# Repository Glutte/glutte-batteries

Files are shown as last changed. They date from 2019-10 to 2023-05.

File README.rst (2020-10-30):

Mesure de l'état de charge de la batterie
=========================================

Les nouvelles (juillet 2019) batteries au plomb nécessitent une nouvelle
approche pour mesurer leur état de charge.

Mesurer la tension ne suffit pas, d'abord parce que la différence de tension
entre batterie pleine et vide est faible, d'autre part parce que la tension
mesurée dépend fortement du courant de dé-/charge.

Proposition
-----------

Mesurer le courant à intervalle régulier (p.ex. à 10Hz) et intégrer le courant
pour calculer une charge accumulée ou extraite de la batterie (A * s = Coulomb).

Besoins
-------

Quand le niveau de charge des batteries est trop bas, il faut couper des
consommateurs. Il est possible de commuter les groupes de consommateurs suivants:

- Balise 70cm
- Mode relais QRP/QRO
- Alimentation Relais
- Alimentation Raspberry Pi, WiFi et autres consommateurs 5V restants

Afin que le relais puisse indiquer le niveau de charge, un port série est
utilisé entre le coulomb-mètre et la glutt-o-matique (unidirectionnel). Pour la
surveillance ainsi que pour d'autres applications, un deuxième port série transmet
les mêmes informations à un Raspberry Pi connecté à Internet.

Le colomb-mètre doit donc comporter trois commutations à relais, qui peuvent à
leur tour commuter des relais de puissance.

Quelques définitions
--------------------

Tension nominale: Tension d'un élément chargé au repos à 25°C : 2.1V/élément soit
12.6V pour la traditionnelle batterie dite de 12V. C'est ce que vous devez lire
(à la précision de la mesure près) sur une batterie que vous avez chargée et
ensuite débranchée pendant une nuit.

Tension de floating (tension de charge d'entretien):
Tension à laquelle on peut maintenir en permanence un accumulateur
pour être sûr qu'il soit chargé au moment où en a besoin : 2.25 à 2.28/élément à
25°C. Cette valeur devrait être corrigée de 0.005V en plus ou en moins par degré
centigrade selon que la température descend ou monte.
A -10°C c'est 2.36V et à +40°C 2.21V.

Tension de recharge:
Tension maximum à laquelle on peut charger la batterie (mais pas la laisser en
permanence). 2.3 à 2.4V/élément toujours à 25°C et avec le même coefficient de
température de 0.005V/°C. Soit 13.8 à 14.4V pour un bloc 12V à 25°C.
Attention à prendre aussi en considération les pics de courte durée si la
tension est bruitée.

Evitez de décharger la batterie en dessous de 11.9V, car vous commencez à
décharger profondément la batterie.

Risque de gel: Une batterie profondément déchargée risque le gel!

+---------+---------------+------------------------+--------------------+
|  Baumé  | Densité H2SO4 | Etat de charge         | Température de gel |
+=========+===============+========================+====================+
| 13 à 23 | 1.099 à 1.190 | Profondément déchargée | entre -7C et -27C  |
+---------+---------------+------------------------+--------------------+
| 24 à 29 | 1.200 à 1.252 | Moyenne                | entre -27C et -52C |
+---------+---------------+------------------------+--------------------+
| 30 à 32 | 1.262 à 1.285 | Pleine                 | plus bas que -52C  |
+---------+---------------+------------------------+--------------------+

Composants
----------

Boitier: Hammond RZ0214C

Shunt: muRata 3020-01096-0

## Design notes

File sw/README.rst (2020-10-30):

Description logiciel
====================

Au démarrage, avant de passer à la mesure régulière, le code doit:

- Initialiser les GPIO
- Mettre en place un timer 100Hz pour pouvoir faire dormir le CPU
- Lire l'EEPROM pour charger le compteur mAh
  - Attention au risque de problemes après 100000 écritures
  - Faire une vérification lecture après écriture et communiquer le problème
- Mettre en place un watchdog
- Initialiser UART (uniquement TX, on verra si on a besoin du RX plus tard)
- Configurer SPI pour le LTC2400
- Initialiser entrées analogiques et mesurer tension batterie
- Initialiser entrée numérique D4 pour mesurer contacts auxiliaires des dijoncteurs des trois phases de l'éolienne.

Protocole du port série
-----------------------

Chaque message commence par un identificateur, suivi d'une virgule, du temps en
secondes, une virgule, un champ de données, et termine par CR LF.

+------------------+---------------------------------------------+
| Identificateur   | Contenu du champ                            |
+------------------+---------------------------------------------+
| `TEXT`           | Un message informatif                       |
| `ERROR`          | Erreur ou avertissement                     |
| `CAPA`           | Une valeur en mAh                           |
| `RELAY`          | Etats des trois relais, `On` ou `Off`       |
| `VBAT+`          | Une valeur en mV                            |
| `VBAT-`          | Une valeur en mV                            |
| `DISJEOL`        | `On` ou `Off`, état du disjoncteur eolienne |
+--------------------+-------------------------------------------+

Par exemple: `TEXT,12,Startup\r\n`

TODO
----

- Definir le comportement par defaut au démarrage, pas de glitch!

Reglages eFuse
--------------

- Low: Horloge crystal 8MHz ou plus, Startup time PWRDWN/RESET 1K/14CK + 4.1ms, diviseur /8 actif
- High: tout par défaut
- Ext: Brownout detector: 4.3V

Commande AVRdude equivalente: `-U lfuse:w:0x7e:m -U hfuse:w:0xd9:m -U efuse:w:0xfc:m`

Remarques
---------

- Le DS18B20 ne sera pas assemblé, l'entrée D4 et son footprint réutilisés pour brancher les auxiliaires des
  disjoncteurs de l'éolienne

Acknowledgements
================

Le dossier `lib/` contient des fichiers des bibliotheques suivantes:

- OneWire https://github.com/PaulStoffregen/OneWire
- DallasTemperature https://github.com/milesburton/Arduino-Temperature-Control-Library.git
- avr-uart https://github.com/andygock/avr-uart
- Code exemple LTC2400 de l'application note correspondante

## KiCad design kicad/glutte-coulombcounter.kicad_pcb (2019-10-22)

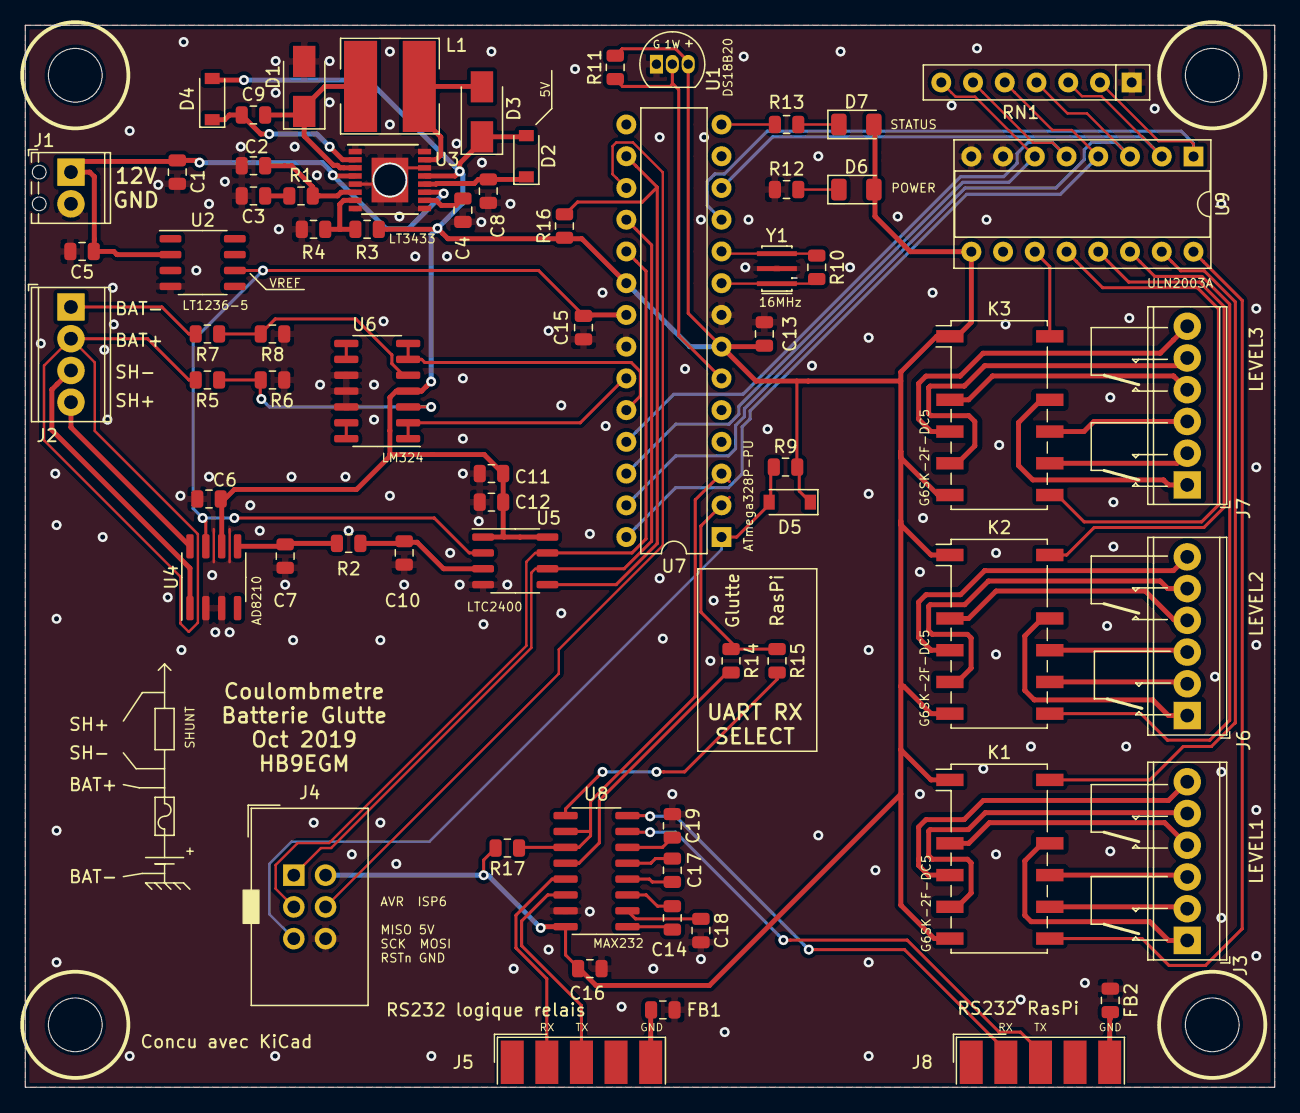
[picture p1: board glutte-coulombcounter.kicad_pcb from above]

Board: 2 copper layers, 100.0 x 85.0 mm, 72 parts (0 on the bottom side), 81 nets.

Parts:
C1: 2.2u; C_0805_2012Metric
C2: 330p; C_0805_2012Metric
C3: 1000p; C_0805_2012Metric
C4: 0.01u; C_0805_2012Metric
C5, C6, C8, C9, C13, C15: 0.1u; C_0805_2012Metric
C7, C10: DNF; C_0805_2012Metric
C11: 4.7u; C_0805_2012Metric
C12: 0.1uF; C_0805_2012Metric
C14, C16, C17, C18, C19: 1u; C_0805_2012Metric
D1: B160-E3; D_SMA
D2, D4, D5: 1N4148; D_SOD-123
D3: B120-E3; D_SMA
D6: LED_PWR; LED_1206_3216Metric
D7: LED_STATUS; LED_1206_3216Metric
FB1, FB2: DNF; L_0805_2012Metric
H1, H2, H3, H4: M4; MountingHole_4.3mm_M4
J1: 12V; TerminalBlock_Phoenix_MPT-0,5-2-2.54_1x02_P2.54mm_Horizontal
J2: Measure; TerminalBlock_Phoenix_MPT-0,5-4-2.54_1x04_P2.54mm_Horizontal
J3: K1; TerminalBlock_Phoenix_MPT-0,5-6-2.54_1x06_P2.54mm_Horizontal
J4: AVR-ISP-6; IDC-Header_2x03_P2.54mm_Vertical
J5: Glutte; DSUB-9_Male_EdgeMount_P2.77mm
J6: K2; TerminalBlock_Phoenix_MPT-0,5-6-2.54_1x06_P2.54mm_Horizontal
J7: K3; TerminalBlock_Phoenix_MPT-0,5-6-2.54_1x06_P2.54mm_Horizontal
J8: Raspi; DSUB-9_Male_EdgeMount_P2.77mm
K1, K2, K3: G6SK-2F-DC5; Relay_DPDT_Omron_G6SK-2F
L1: 100uH; Sumida_CDRH6D28
R1: 68k; R_0805_2012Metric
R2: 51; R_0805_2012Metric
R3: 300k; R_0805_2012Metric
R4: 97.6k; R_0805_2012Metric
R5, R7: 300k/1%; R_0805_2012Metric
R6, R8: 100k/1%; R_0805_2012Metric
R9: 10k; R_0805_2012Metric
R10: 1M; R_0805_2012Metric
R11, R16, R17: 4k7; R_0805_2012Metric
R12, R13: 330; R_0805_2012Metric
R14: 0R; R_0805_2012Metric
R15: DNF; R_0805_2012Metric
RN1: 2k2; R_Array_SIP7
U1: DS18B20; TO-92_Inline
U2: LT1236-5; SO-8_3.9x4.9mm_P1.27mm
U3: LT3433; TSSOP-16-1EP_4.4x5mm_P0.65mm
U4: AD8210; SOIC-8_3.9x4.9mm_P1.27mm
U5: LTC2400; SO-8_3.9x4.9mm_P1.27mm
U6: LM324; SOIC-14_3.9x8.7mm_P1.27mm
U7: ATmega328P-PU; DIP-28_W7.62mm
U8: MAX232; SOIC-16_3.9x9.9mm_P1.27mm
U9: ULN2003A; DIP-16_W7.62mm_Socket
Y1: CSTNE16M0V530000R0; Resonator_SMD_muRata_CSTxExxV-3Pin_3.0x1.1mm_HandSoldering

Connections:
+5VA: C6.1, C11.1, C12.1, C13.1, C16.1, D2.2, D3.1, D4.2, D5.1, D6.2, D7.2, J4.2, K1.1, K1.6, K2.1, K2.6, K3.1, K3.6, R3.2, R9.2, R11.2, R16.1, R17.2, U1.3, U3.13, U4.6, U5.1, U5.8, U6.4, U7.7, U7.20, U8.16, U9.9
+12V: C1.1, C5.1, J1.1, U2.2, U3.4, U3.11
+BATT: J2.2, R5.2
-BATT: J2.1, R7.2
/1WIRE: R11.1, U1.2, U7.6
/ADC0: U6.1, U6.2, U7.23
/ADC1: U6.6, U6.7, U7.24
/MISO: J4.1, U5.6, U7.18
/MOSI: J4.4, U7.17
/RESETn: D5.2, J4.5, R9.1, U7.1
/RXD: R14.1, R15.1, U7.2
/Relays/K1_RESET: RN1.2, U7.11, U9.1
/Relays/K1_SET: RN1.3, U7.12, U9.2
/Relays/K2_RESET: RN1.4, U7.27, U9.3
/Relays/K2_SET: RN1.5, U7.28, U9.4
/Relays/K3_RESET: RN1.6, U7.25, U9.5
/Relays/K3_SET: RN1.7, U7.26, U9.6
/SCK: J4.3, U5.7, U7.19
/SHUNT+: J2.4, U4.8
/SHUNT-: J2.3, U4.1
/SSn: R16.2, U5.5, U7.16
/STATUS: R13.2, U7.14
/TXD: R17.1, U7.3, U8.10, U8.11
GNDA: C1.2, C2.2, C3.2, C4.2, C5.2, C6.2, C7.2, C8.1, C10.2, C11.2, C12.2, C13.2, C15.2, C16.2, C18.2, C19.1, D1.2, FB1.1, FB2.1, J1.2, J4.6, R4.1, R6.1, R8.1, R12.1, RN1.1, U1.1, U2.4, U3.1, U3.5, U3.8, U3.9, U3.14, U3.16, U3.17, U4.2, U4.3, U5.4, U6.10, U6.11, U6.12, U7.8, U7.22, U8.15, U9.7, U9.8, Y1.2
unnamed: C2.1, R1.2, U3.6
unnamed: C3.1, R1.1
unnamed: C4.1, U3.10
unnamed: C7.1, R2.2, U4.5
unnamed: C8.2, D2.1, U3.12
unnamed: C9.1, D4.1, U3.2
unnamed: C9.2, D1.1, L1.1, U3.3
unnamed: C10.1, R2.1, U5.3
unnamed: C14.1, U8.1
unnamed: C14.2, U8.3
unnamed: C17.1, U8.4
unnamed: C17.2, U8.5
unnamed: C18.1, U8.2
unnamed: C19.2, U8.6
unnamed: D3.2, L1.2, U3.15
unnamed: D6.1, R12.2
unnamed: D7.1, R13.1
unnamed: FB1.2, J5.5
unnamed: FB2.2, J8.5
unnamed: J3.1, K1.10
unnamed: J3.2, K1.8
unnamed: J3.3, K1.9
unnamed: J3.4, K1.3
unnamed: J3.5, K1.5
unnamed: J3.6, K1.4
unnamed: J5.2, U8.13
unnamed: J5.3, U8.14
unnamed: J6.1, K2.10
unnamed: J6.2, K2.8
unnamed: J6.3, K2.9
unnamed: J6.4, K2.3
unnamed: J6.5, K2.5
unnamed: J6.6, K2.4
unnamed: J7.1, K3.10
unnamed: J7.2, K3.8
unnamed: J7.3, K3.9
unnamed: J7.4, K3.3
unnamed: J7.5, K3.5
unnamed: J7.6, K3.4
unnamed: J8.2, U8.8
unnamed: J8.3, U8.7
unnamed: K1.7, U9.16
unnamed: K1.12, U9.15
unnamed: K2.7, U9.14
unnamed: K2.12, U9.13
unnamed: K3.7, U9.12
unnamed: K3.12, U9.11
unnamed: R3.1, R4.2, U3.7
unnamed: R5.1, R6.2, U6.3
unnamed: R7.1, R8.2, U6.5
unnamed: R10.1, U7.10, Y1.3
unnamed: R10.2, U7.9, Y1.1
unnamed: R14.2, U8.12
unnamed: R15.2, U8.9
unnamed: U6.8, U6.9
unnamed: U6.13, U6.14
VREF: C15.1, U2.6, U4.7, U5.2, U7.21

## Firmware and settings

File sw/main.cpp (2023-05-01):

/*
 * The MIT License (MIT)
 *
 * Copyright (c) 2020 Matthias P. Braendli
 *
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
 * THE SOFTWARE IS PROVIDED "AS IS", WITHOUT WARRANTY OF ANY KIND, EXPRESS OR
 * IMPLIED, INCLUDING BUT NOT LIMITED TO THE WARRANTIES OF MERCHANTABILITY,
 * FITNESS FOR A PARTICULAR PURPOSE AND NONINFRINGEMENT. IN NO EVENT SHALL THE
 * AUTHORS OR COPYRIGHT HOLDERS BE LIABLE FOR ANY CLAIM, DAMAGES OR OTHER
 * LIABILITY, WHETHER IN AN ACTION OF CONTRACT, TORT OR OTHERWISE, ARISING FROM,
 * OUT OF OR IN CONNECTION WITH THE SOFTWARE OR THE USE OR OTHER DEALINGS IN THE
 * SOFTWARE.
*/

#include "config.h"

#include <stdlib.h>
#include <stdint.h>
#include <stdio.h>
#include <math.h>

#include <avr/pgmspace.h>
#include <avr/io.h>
#include <avr/interrupt.h>
#include <avr/sleep.h>
#include <avr/eeprom.h>
#include <avr/wdt.h>

#include "common.hpp"
#include "pins.hpp"
#include "relays.hpp"
#include "ltc2400.h"

extern "C" {
#include "uart.h"
}

// UART endline is usually CR LF
#define ENDL "\r\n"

constexpr double R_SHUNT = 1e-3; // Ohm

/* Capacity counters and thresholds, in As (= Coulombs)
 *
 * For every relay, define a threshold below which the
 * relay should be active.
 */
constexpr double THRESHOLD_K1 = 1550.0 * 3600;
constexpr double THRESHOLD_K2 = 1300.0 * 3600;
constexpr double THRESHOLD_K3 = 800.0 * 3600;
constexpr double THRESHOLD_HYSTERESIS = 50.0 * 3600;

constexpr double THRESHOLD_K1_UP = THRESHOLD_K1 + THRESHOLD_HYSTERESIS;
constexpr double THRESHOLD_K2_UP = THRESHOLD_K2 + THRESHOLD_HYSTERESIS;
constexpr double THRESHOLD_K3_UP = THRESHOLD_K3 + THRESHOLD_HYSTERESIS;

constexpr double THRESHOLD_K1_DOWN = THRESHOLD_K1;
constexpr double THRESHOLD_K2_DOWN = THRESHOLD_K2;
constexpr double THRESHOLD_K3_DOWN = THRESHOLD_K3;

constexpr uint32_t MAX_CAPACITY = 1650uL * 3600uL; // As
constexpr uint32_t STARTUP_CAPACITY = 1550uL * 3600uL; // As

static uint32_t current_capacity;
static uint32_t previous_capacity;
static bool relay_state_known = false;
static bool relay_k1_set = false;
static bool relay_k2_set = false;
static bool relay_k3_set = false;

/* Storage of battery capacity in mC.
 * 3600 mC = 1mAh */

/* Store the capacity three times in EEPROM, and check data validity using majority vote */
uint32_t EEMEM stored_capacity1;
uint32_t EEMEM stored_capacity2;
uint32_t EEMEM stored_capacity3;

/* Store timestamp of previous execution of a subroutine.
 * Subroutines scheduled in second intervals don't need to
 * be stored as timer_t, to save some space and simplify
 * the comparison.
 */
static uint32_t last_store_time_seconds;
static uint32_t last_threshold_calculation_seconds;
static uint32_t last_status_print_seconds;
static uint32_t last_disjoncteur_print_seconds;
static timer_t last_ltc2400_measure;

enum class adc_state_t {
    IDLE,
    PENDING_ADC0,
    PENDING_ADC1,
};

static adc_state_t adc_state;
static uint32_t last_adc_measure_time_seconds;

/* Raw values from the ADC.
 * The ADC converts an analog input voltage to a 10-bit digital value through
 * successive approximation. The minimum value represents GND and the maximum
 * value represents the voltage on the AREF pin minus 1 LSB.
 * (datasheet 24.2)
 */
const uint32_t V_REF_mV = 5000;

#define ADC_VALUE_TO_MILLIVOLT(val) ((uint32_t)val * V_REF_mV) / (uint32_t)(1<<10)

// Use the LDO on Vref as ADC reference, set REFS1..REFS0 = 0b00, and ADC input 0
#define SET_ADMUX(input) ADMUX = (input & 0x0F)

/* Timer at approximately 100ms.
 *
 * Setup 100Hz timer, assuming F_CPU at 16MHz / 8:
 *
 * overflow for 100ms: F_CPU [ticks/s] / prescaler [unitless] * interval [s] = [ticks/s*s] = [ticks]
 * interval [s] = 0.1 = 1 / 10
 *
 * Actual interval after rounding:
 * interval [s] = overflow [ticks] / (F_CPU [ticks/s] / prescaler [unit-less])
 *              = 99.84 ms
 */
constexpr uint8_t TIMER_OVERFLOW = (uint8_t)(F_CPU / 1024 / 10); // 2e6 / 1024 / 10 = 195.3125
constexpr double TIMER_TICK_INTERVAL = (double)TIMER_OVERFLOW / ((double)F_CPU / 1024.0); // 195 / (2e6 / 1024) = 99.84ms
constexpr uint32_t TIMER_TICK_INTERVAL_US = (uint32_t)(TIMER_TICK_INTERVAL * 1e6);

/* Since this timer is updated in an ISR, care has to be taken
 * when reading it, because all operations involving variables
 * larger than 1 byte are not atomic on AVR.
 */
static timer_t system_timer;

/* At reset, save the mcusr register to find out why we got reset.
 * Datasheet 11.9.1, example code from wdt.h */
uint8_t mcusr_mirror __attribute__ ((section (".noinit")));

// Convert from As to mAh
inline uint32_t As_to_mAh(uint32_t value)
{
    float cap = value;
    cap /= 3600.0f;
    cap *= 1000.0f;
    return lrintf(cap);
}

ISR(TIMER0_COMPA_vect)
{
    system_timer += timer_t{0, TIMER_TICK_INTERVAL_US};
}

enum class error_type_t {
    EEPROM_READ_WARNING,
    EEPROM_READ_ERROR,
    EEPROM_WRITE_ERROR,
    LTC2400_NOT_READY,
    LTC2400_DMY_BIT_FAULT,
    LTC2400_EXTENDED_RANGE_ERROR,
    RELAY_NOT_SET,
};

static void flag_error(const error_type_t e);

static char timestamp_buf[32];
static void send_message(const char *message)
{
    snprintf(timestamp_buf, sizeof(timestamp_buf), "TEXT,%ld,", system_timer.get_seconds_atomic());
    uart_puts(timestamp_buf);
    uart_puts(message);
    uart_puts_P(ENDL);
}

#define send_debug(x) send_message(x)

static void send_relay_states(const timer_t& time)
{
    snprintf(timestamp_buf, sizeof(timestamp_buf), "RELAY,%ld,%s,%s,%s" ENDL,
            time.get_seconds_atomic(),
            relay_k1_set ? "On" : "Off",
            relay_k2_set ? "On" : "Off",
            relay_k3_set ? "On" : "Off");
    uart_puts(timestamp_buf);
}

static void send_capacity(uint32_t capacity, const timer_t& time)
{
    snprintf(timestamp_buf, sizeof(timestamp_buf), "CAPA,%ld,%ld" ENDL, time.get_seconds_atomic(), capacity);
    uart_puts(timestamp_buf);
}

enum class adc_voltage_id {
    V_BAT_PLUS,
    V_BAT_MINUS,
};

static void send_voltage(uint32_t millivolts, adc_voltage_id voltage_id, const timer_t& time)
{
    snprintf(timestamp_buf, sizeof(timestamp_buf), "VBAT%c,%ld,%ld" ENDL,
            voltage_id == adc_voltage_id::V_BAT_PLUS ? '+' : '-',
            time.get_seconds_atomic(), millivolts);
    uart_puts(timestamp_buf);
}

static void send_disjoncteur_state(bool state, const timer_t& time)
{
    snprintf(timestamp_buf, sizeof(timestamp_buf), "DISJEOL,%ld,%s" ENDL,
            time.get_seconds_atomic(),
            state ? "On" : "Off");
    uart_puts(timestamp_buf);
}


static void load_capacity_from_eeprom()
{
    /* Store the same value three times to make
     * a majority vote to detect errors
     */
    uint32_t cap1 = eeprom_read_dword(&stored_capacity1);
    uint32_t cap2 = eeprom_read_dword(&stored_capacity2);
    uint32_t cap3 = eeprom_read_dword(&stored_capacity3);

    if (cap1 == cap2 and cap2 == cap3) {
        current_capacity = cap1;
    }
    else if (cap1 == cap2) {
        flag_error(error_type_t::EEPROM_READ_WARNING);
        current_capacity = cap1;
        eeprom_write_dword(&stored_capacity3, cap1);
    }
    else if (cap1 == cap3) {
        flag_error(error_type_t::EEPROM_READ_WARNING);
        current_capacity = cap1;
        eeprom_write_dword(&stored_capacity2, cap1);
    }
    else if (cap2 == cap3) {
        flag_error(error_type_t::EEPROM_READ_WARNING);
        current_capacity = cap2;
        eeprom_write_dword(&stored_capacity1, cap1);
    }
    else {
        flag_error(error_type_t::EEPROM_READ_ERROR);
        current_capacity = cap2; // arbitrary
    }

    if (current_capacity == 0xFFffFFff) {
        /* EEPROM does not contain a valid value */
        current_capacity = STARTUP_CAPACITY;
    }

    previous_capacity = current_capacity;
}

static void store_capacity_to_eeprom()
{
    eeprom_write_dword(&stored_capacity1, current_capacity);
    eeprom_write_dword(&stored_capacity2, current_capacity);
    eeprom_write_dword(&stored_capacity3, current_capacity);

    if (eeprom_read_dword(&stored_capacity1) != current_capacity or
        eeprom_read_dword(&stored_capacity2) != current_capacity or
        eeprom_read_dword(&stored_capacity3) != current_capacity) {
        flag_error(error_type_t::EEPROM_WRITE_ERROR);
    }
}

static void handle_thresholds(const timer_t& time_now)
{
    if (not relay_state_known) {
        /* At bootup, ignore hysteresis. Put all relays in the state defined by the
         * thresholds.
         */
        relay_k1_set = current_capacity < THRESHOLD_K1;
        relay_k2_set = current_capacity < THRESHOLD_K2;
        relay_k3_set = current_capacity < THRESHOLD_K3;

        bool success = relays_toggle(relay_id_t::K1, relay_k1_set, time_now);
        success &= relays_toggle(relay_id_t::K2, relay_k2_set, time_now);
        success &= relays_toggle(relay_id_t::K3, relay_k3_set, time_now);
        relay_state_known = success;

        if (not success) {
            flag_error(error_type_t::RELAY_NOT_SET);
        }
    }
    else {
        bool success = true;

        if (previous_capacity < THRESHOLD_K1_UP and current_capacity >= THRESHOLD_K1_UP) {
            relay_k1_set = false;
            success &= relays_toggle(relay_id_t::K1, false, time_now);
        }

        if (previous_capacity > THRESHOLD_K1_DOWN and current_capacity <= THRESHOLD_K1_DOWN) {
            relay_k1_set = true;
            success &= relays_toggle(relay_id_t::K1, true, time_now);
        }

        if (previous_capacity < THRESHOLD_K2_UP and current_capacity >= THRESHOLD_K2_UP) {
            relay_k2_set = false;
            success &= relays_toggle(relay_id_t::K2, false, time_now);
        }

        if (previous_capacity > THRESHOLD_K2_DOWN and current_capacity <= THRESHOLD_K2_DOWN) {
            relay_k2_set = true;
            success &= relays_toggle(relay_id_t::K2, true, time_now);
        }

        if (previous_capacity < THRESHOLD_K3_UP and current_capacity >= THRESHOLD_K3_UP) {
            relay_k3_set = false;
            success &= relays_toggle(relay_id_t::K3, false, time_now);
        }

        if (previous_capacity > THRESHOLD_K3_DOWN and current_capacity <= THRESHOLD_K3_DOWN) {
            relay_k3_set = true;
            success &= relays_toggle(relay_id_t::K3, true, time_now);
        }

        if (not success) {
            flag_error(error_type_t::RELAY_NOT_SET);
        }
    }

    previous_capacity = current_capacity;
}

static void flag_error(const error_type_t e)
{
    snprintf(timestamp_buf, sizeof(timestamp_buf), "ERROR,%ld,", system_timer.get_seconds_atomic());
    uart_puts(timestamp_buf);
    switch (e) {
        case error_type_t::EEPROM_READ_WARNING:
            uart_puts_P("EEPRON read warning" ENDL);
            break;
        case error_type_t::EEPROM_READ_ERROR:
            uart_puts_P("EEPRON read error" ENDL);
            break;
        case error_type_t::EEPROM_WRITE_ERROR:
            uart_puts_P("EEPRON write error" ENDL);
            break;
        case error_type_t::LTC2400_NOT_READY:
            uart_puts_P("LTC2400 not ready" ENDL);
            break;
        case error_type_t::LTC2400_DMY_BIT_FAULT:
            uart_puts_P("LTC2400 DMY bit error" ENDL);
            break;
        case error_type_t::LTC2400_EXTENDED_RANGE_ERROR:
            uart_puts_P("LTC2400 extended range error" ENDL);
            break;
        case error_type_t::RELAY_NOT_SET:
            uart_puts_P("RELAYS not set" ENDL);
            break;
    }
}

int main()
{
    /* Save the reset source for debugging, then enable the watchdog.
     * Attention: WDT may be already enabled if it triggered a reset!
     * Datasheet 11.8.2 */
    mcusr_mirror = MCUSR;
    MCUSR = 0;
    wdt_reset();
    wdt_enable(WDTO_4S);

    /* Setup GPIO */
    // Active-low outputs must be high
    // PINB_SPI_SCK must be low (See ltc2400.h)
    PORTB = PINB_INIT;
    PORTC = PINC_INIT;
    PORTD = PIND_INIT;

    // Enable output
    DDRB = PINB_OUTPUTS;
    DDRC = PINC_OUTPUTS;
    DDRD = PIND_OUTPUTS;

    pins_set_status(true);

    relays_init();

    // Initialise SPI and LTC2400
    ltc2400_init();

    // Enable ADC
    ADCSRA |= _BV(ADEN);
    SET_ADMUX(0);

    // Warning: Bi-stable relays are still in unknown state!

    /* Setup UART */
    uart_init(UART_BAUD_SELECT(9600, F_CPU));
    if (mcusr_mirror & WDRF) {
        send_message("Startup after WDT reset");
    }
    else if (mcusr_mirror & BORF) {
        send_message("Startup after brown-out");
    }
    else if (mcusr_mirror & EXTRF) {
        send_message("Startup after external reset");
    }
    else if (mcusr_mirror & PORF) {
        send_message("Startup after power-on reset");
    }
    else {
        send_message("Startup");
    }

#if 0
    current_capacity = 1023uL * 3600uL;
    store_capacity_to_eeprom();
    while (true) {}
#endif

    system_timer = timer_t(0, 0);

    /* Load capacity stored in EEPROM */
    current_capacity = 0;
    load_capacity_from_eeprom();

    snprintf(timestamp_buf, sizeof(timestamp_buf), "TEXT,%d,Load EEPROM %lu" ENDL, 0, As_to_mAh(current_capacity));
    uart_puts(timestamp_buf);

    last_ltc2400_measure = system_timer;

    last_store_time_seconds =
        last_status_print_seconds =
        last_disjoncteur_print_seconds =
        last_adc_measure_time_seconds =
        last_threshold_calculation_seconds = system_timer.get_seconds_atomic();

    adc_state = adc_state_t::IDLE;

    /* Enable timer and interrupts */
    TCCR0A |= _BV(WGM01); // Set timer mode to CTC (datasheet 15.7.2)
    TIMSK0 |= _BV(OCIE0A); // enable overflow interrupt
    OCR0A = TIMER_OVERFLOW;
    TCCR0B |= _BV(CS02) | _BV(CS00); // Start timer at Fcpu/1024
    sei();
    send_debug("Timer started");

    // Accumulate in floating point
    double capacity_accum = current_capacity;

    /* Put the CPU to sleep */
    set_sleep_mode(SLEEP_MODE_IDLE);

    send_debug("Sleep configured");
    while (true) {
        pins_set_status(false);
        sleep_mode();
        wdt_reset();
        pins_set_status(true);

        /* In every loop, access the system_timer only once, so that
         * every loop has a well-defined time */
        const auto time_now = system_timer.get_atomic_copy();

#if ENABLE_STORE_TO_EEPROM
        /* EEPROM has an endurance of at least 100'000 write/erase cycles.
         * (Datasheet 8.4 EEPROM Data Memory)
         * Storing every five hours gives us several years of endurance.
         * */
        if (last_store_time_seconds + 3600 * 5 <= time_now.seconds_) {
            send_debug("Store to EEPROM");
            store_capacity_to_eeprom();
        }
#endif
        const auto ltc2400_measure_interval = timer_t{0, 200000uL};
        if (last_ltc2400_measure + ltc2400_measure_interval < time_now) {
            last_ltc2400_measure += ltc2400_measure_interval;

            if (ltc2400_conversion_ready()) {
                bool dmy_fault = false;
                bool exr_fault = false;
                uint32_t adc_value = 0;
                const double adc_voltage = ltc2400_get_conversion_result(dmy_fault, exr_fault, adc_value);

                if (dmy_fault) {
                    flag_error(error_type_t::LTC2400_DMY_BIT_FAULT);
                }

                if (exr_fault) {
                    flag_error(error_type_t::LTC2400_EXTENDED_RANGE_ERROR);
                }

                /* Vout - 2.5V = Ishunt * Rshunt * 20 */
                const double i_shunt = (adc_voltage - 2.5) / (20.0 * R_SHUNT);
                capacity_accum += i_shunt * ltc2400_measure_interval.microsecs_ * 1e-6;

#if DEBUG_MEASUREMENT
                snprintf(timestamp_buf, sizeof(timestamp_buf), "DBG,%ldmV,%ldmA" ENDL,
                        lrint((adc_voltage - 2.5) * 1e3),
                        lrint(i_shunt * 1e3));
                uart_puts(timestamp_buf);
#endif

                if (capacity_accum < 0) { capacity_accum = 0; }
                if (capacity_accum > MAX_CAPACITY) { capacity_accum = MAX_CAPACITY; }

                current_capacity = lrint(capacity_accum);
            }
            else {
                flag_error(error_type_t::LTC2400_NOT_READY);
            }
        }

        constexpr auto threshold_calculation_interval_s = 4;
        if (last_threshold_calculation_seconds + threshold_calculation_interval_s < time_now.seconds_) {
            last_threshold_calculation_seconds += threshold_calculation_interval_s;
            handle_thresholds(time_now);
        }

        constexpr auto status_print_interval = 10;
        if (last_status_print_seconds + status_print_interval < time_now.seconds_) {
            last_status_print_seconds += status_print_interval;
            send_capacity(As_to_mAh(current_capacity), time_now);
            send_relay_states(time_now);
        }

        // Input is divided by 4 by LM324. ADC is 10-bit,
        // value 0 is GND, value (1<<10) is Vref
        constexpr auto adc_interval_s = 20;
        switch (adc_state) {
            case adc_state_t::IDLE:
                if (last_adc_measure_time_seconds + adc_interval_s < time_now.seconds_) {
                    last_adc_measure_time_seconds += adc_interval_s;
                    SET_ADMUX(0);
                    // Start ADC conversion
                    ADCSRA |= _BV(ADSC);
                    adc_state = adc_state_t::PENDING_ADC0;
                }
                break;
            case adc_state_t::PENDING_ADC0:
                // ADSC is cleared when the conversion finishes
                if ((ADCSRA & ADSC) == 0) {
                    // BAT+

                    // Datasheet 24.9.3 says ADCL must be read first
                    const uint8_t adcl = ADCL;
                    const uint16_t adc_value_0 = ((uint16_t)ADCH << 8) | adcl;
                    send_voltage(ADC_VALUE_TO_MILLIVOLT(adc_value_0) * 4, adc_voltage_id::V_BAT_PLUS, time_now);
                    SET_ADMUX(1);
                    // Start ADC conversion
                    ADCSRA |= _BV(ADSC);

                    adc_state = adc_state_t::PENDING_ADC1;
                }
                break;
            case adc_state_t::PENDING_ADC1:
                // ADSC is cleared when the conversion finishes
                if ((ADCSRA & ADSC) == 0) {
                    // BAT-
                    const uint8_t adcl = ADCL;
                    const uint16_t adc_value_1 = ((uint16_t)ADCH << 8) | adcl;
                    adc_state = adc_state_t::IDLE;

                    send_voltage(ADC_VALUE_TO_MILLIVOLT(adc_value_1) * 4, adc_voltage_id::V_BAT_MINUS, time_now);
                }
                break;
        }

        constexpr auto disjoncteur_measure_interval = 60;
        if (last_disjoncteur_print_seconds + disjoncteur_measure_interval < time_now.seconds_) {
            last_disjoncteur_print_seconds += disjoncteur_measure_interval;
            send_disjoncteur_state(pins_read_disjoncteur_eolienne(), time_now);
        }

        relays_handle(time_now);
    }

    return 0;
}

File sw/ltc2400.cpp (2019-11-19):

/*
 * The MIT License (MIT)
 *
 * Copyright (c) 2019 Matthias P. Braendli
 *
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
 * THE SOFTWARE IS PROVIDED "AS IS", WITHOUT WARRANTY OF ANY KIND, EXPRESS OR
 * IMPLIED, INCLUDING BUT NOT LIMITED TO THE WARRANTIES OF MERCHANTABILITY,
 * FITNESS FOR A PARTICULAR PURPOSE AND NONINFRINGEMENT. IN NO EVENT SHALL THE
 * AUTHORS OR COPYRIGHT HOLDERS BE LIABLE FOR ANY CLAIM, DAMAGES OR OTHER
 * LIABILITY, WHETHER IN AN ACTION OF CONTRACT, TORT OR OTHERWISE, ARISING FROM,
 * OUT OF OR IN CONNECTION WITH THE SOFTWARE OR THE USE OR OTHER DEALINGS IN THE
 * SOFTWARE.
*/

/* Essential information from datasheet:
 *
 * SCK mode:
 * The internal or external SCK mode is selected on power-up and then
 * reselected every time a HIGH-to-LOW transition is detected at the CS pin. If
 * SCK is HIGH or floating at power-up or during this transition, the
 * converter enters the internal SCK mode. If SCK is LOW at power-up or
 * during this transition, the converter enters the external SCK mode.
 *
 * CS:
 * At any time during the conversion cycle, CS may be pulled LOW in order to
 * monitor the state of the converter.  While CS is pulled LOW, EOC is output
 * to the SDO pin. EOC = 1 while a conversion is in progress and EOC = 0 if the
 * device is in the sleep state. Independent of CS, the device automatically
 * enters the low power sleep state once the conversion is complete.
 *
 * The device remains in the sleep state until the first rising edge of SCK is
 * seen while CS is LOW.
 *
 * We must latch incoming data on the rising edge of SCK.
 *
 * On the 32nd falling edge of SCK, the device begins a new conversion.
 *
 * The sub LSBs are valid conversion results beyond the 24-bit level that may
 * be included in averaging or discarded without loss of resolution.
 *
 * Output format, 32 bits in total:
 * EOC, DMY, SIG, EXR, MSB..LSB (24 bits), SUB-LSB(4 bits)
 *
 * - EOC goes low when the conversion is complete
 * - DMY is always low
 * - SIG is 1 when Vin > 0
 * - EXR is 0 when 0 <= Vin <= Vref
 *
 *
 * We will use External SCK, Single Cycle Conversion (see table 4):
 * - SCK must be low on falling edge of CSn
 * - We will discard the sub LSB
 * - We will check that DMY is always 0, SIG always 1 and EXR always 0
 *
*/

#include <avr/io.h>
#include <avr/interrupt.h>
#include <util/delay.h>
#include "ltc2400.h"

static void cs_low()
{
    cli();
    PORTB &= ~PINB_SPI_LTC_CSn;
    sei();
}

static void cs_high()
{
    cli();
    PORTB |= PINB_SPI_LTC_CSn;
    sei();
}

static void spi_en()
{
    cli();
    // Set SPI Enable and Master mode,
    // bit order=MSB first (DORD=0),
    // SPI mode=0 (CPOL=0, CPHA=0)
    //
    // clock divider:
    // SPR1 and SPR0 are the two LSB bits in SPCR
    // SPR1 SPR0 ~SPI2X Freq
    //   0    0     0   fosc/2
    //   0    1     0   fosc/8
    //   1    0     0   fosc/32
    //   1    1     0   fosc/64
    // double speed mode:
    //   0    0     1   fosc/4
    //   0    1     1   fosc/16
    //   1    0     1   fosc/64
    //   1    1     1   fosc/128
    //
    // Set SPR0 for /8
    SPCR = _BV(SPE) | _BV(MSTR) | _BV(SPR0);
    SPSR = 0; // clear SPI2X
    sei();
}

static void spi_dis()
{
    cli();
    PORTB &= ~PINB_SPI_SCK;
    SPCR = _BV(MSTR) | _BV(SPR1);
    sei();
}

void ltc2400_init()
{
    cli();
    PORTB |= PINB_SPI_LTC_CSn;
    // Ensure CLK is low so that the device doesn't enter internal SCK mode
    PORTB &= ~PINB_SPI_SCK;
    sei();
}

bool ltc2400_conversion_ready()
{
    cs_low();

    _delay_us(100);

    // EOC == 0 means conversion is complete and device in sleep mode
    return not (PINB & PINB_SPI_MISO);
}

double ltc2400_get_conversion_result(bool& dmy_fault, bool& exr_fault, uint32_t& raw_value)
{
    spi_en();
    cs_low();

    _delay_us(100);

    uint8_t data[4] = {};

    for (int i = 0; i < 4; i++) {
        SPDR = 0x0; // always output 0

        while (!(SPSR & _BV(SPIF))) { /* wait */ }
        data[i] = SPDR;
    }

    spi_dis();
    cs_high();

    raw_value =
        ((uint32_t)data[0] << 24) |
        ((uint32_t)data[1] << 16) |
        ((uint32_t)data[2] << 8) |
        ((uint32_t)data[3]);

    dmy_fault = raw_value & (1uL << 30);
    exr_fault = raw_value & (1uL << 28);

    // Mask 4 MSB status bits, and shift out 4 sub-LSB bits
    const uint32_t adc_value = (raw_value >> 4) & 0x00FFFFFF;

    // Convert ADC value to voltage
    return (double)adc_value / ((double)0x00FFFFFF / 5.0f);
}

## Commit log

2019-07-24 Add first schematic
    [glutte-coulombcounter.sch]
2019-07-24 Set footprints, add LEDs
    [glutte-coulombcounter.sch]
2019-07-24 Place and route PCB
    [glutte-coulombcounter.kicad_pcb, glutte-coulombcounter.sch]
2019-07-24 Change LM324 footprint to SOIC
    [glutte-coulombcounter.kicad_pcb, glutte-coulombcounter.sch]
2019-07-24 Rework some routing
    [glutte-coulombcounter.kicad_pcb]
2019-08-19 Update TODO, minor routing
    [glutte-coulombcounter.kicad_pcb, glutte-coulombcounter.sch]
2019-09-09 Move power supply to separate sheet
    [glutte-coulombcounter.kicad_pcb, glutte-coulombcounter.sch, power.sch]
2019-09-09 Add relays
    [glutte-coulombcounter.kicad_pcb, glutte-coulombcounter.sch, relays.sch]
2019-10-18 Add second UART output for Raspi
    [glutte-coulombcounter.kicad_pcb, glutte-coulombcounter.sch, power.sch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]
2019-10-19 Add resistor network on relay control signals
    [glutte-coulombcounter.kicad_pcb, relays.sch]
2019-10-19 Add pullups on CSn and UART TX
    [glutte-coulombcounter.kicad_pcb, glutte-coulombcounter.sch]
2019-10-19 Add timer initialisation
2019-10-19 Restructure lib, add uart
2019-10-21 Change R and C to 0805, improve silkscreen
    [glutte-coulombcounter.kicad_pcb, glutte-coulombcounter.sch, power.sch]
2019-10-21 Run DRC and ERC
    [glutte-coulombcounter.kicad_pcb]
2019-10-22 Minor routing changes
    [glutte-coulombcounter.kicad_pcb]
2019-10-22 Correct wrong DCDC inductor
    [glutte-coulombcounter.kicad_pcb, glutte-coulombcounter.sch, power.sch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]
2019-10-22 Add Ampere to back silkscreen and update MPN
    [glutte-coulombcounter.kicad_pcb, glutte-coulombcounter.sch, power.sch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]
2019-10-24 Pull in some Arduino code so that libraries are easier to use
2019-10-26 Add preliminary mAh accumulator
    [glutte-coulombcounter.sch]
2019-10-26 Print out current_capacity
2019-11-03 Move timer stuff to common
2019-11-03 Add relay toggle code
2019-11-03 Rework timer_t to use microseconds
    [main.cpp, relays.cpp]
2019-11-04 Specify MAX232 package
    [glutte-coulombcounter.sch]
2019-11-17 Add ADC measurements
2019-11-17 Fix fuse settings to use crystal, not ext clock
2019-11-17 Use correct ISR for timer
    [main.cpp]
2019-11-17 Add debug and wdt reset inside loop
    [main.cpp]
2019-11-17 Change type of relay hold time variable
2019-11-17 Fix CAPACITY length print
    [main.cpp]
2019-11-17 Replace C11 by 2.2uF instead of 4.7uF
    [glutte-coulombcounter.sch, power.sch, relays.sch]
2019-11-17 Additional changes in SPI
2019-12-28 Refresh schematic library
    [glutte-coulombcounter.sch]
2019-12-28 Use explicit enum for battery voltage measurements
2019-12-29 Set proper ADC reference selection
2020-04-16 Check relay toggling functionality
2020-04-25 Fix loading of EEPROM and As to mAh conversion
    [main.cpp]
2020-04-25 Status LED shows CPU sleeping
2020-05-03 Output Relay state
2021-02-25 Properly setup CTC mode for timer
    The previous setup was out of spec, and overflowed at 255 instead of 195
2023-05-01 Change startup capacity
